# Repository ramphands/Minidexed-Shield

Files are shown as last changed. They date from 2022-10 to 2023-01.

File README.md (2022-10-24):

# Minidexed-Shield
A shield for a Raspberry Pi (Model 3) running [Minidexed](https://github.com/probonopd/MiniDexed/)
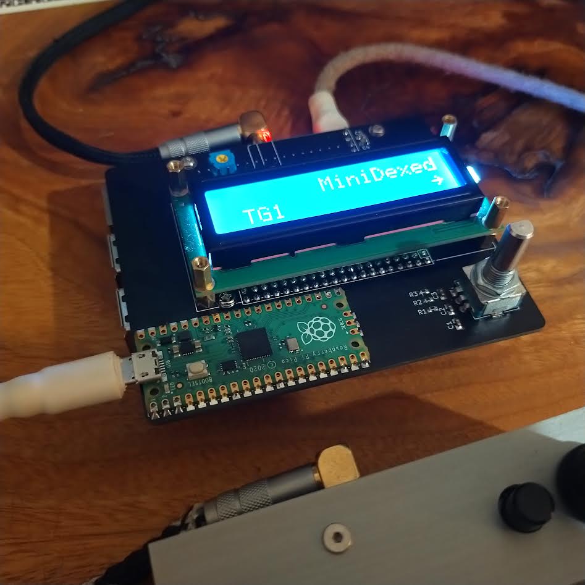
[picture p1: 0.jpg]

image of the shield in use

A Pi Pico is used as a Host to Host connection, allowing sequencing via PC or other host device.  Code obtained from [rsta2's "midi_adapter" Pico repo](https://github.com/rsta2/pico)

Please use the minixeded.ini file in this repo as the encoder pinout is different from the stock .ini

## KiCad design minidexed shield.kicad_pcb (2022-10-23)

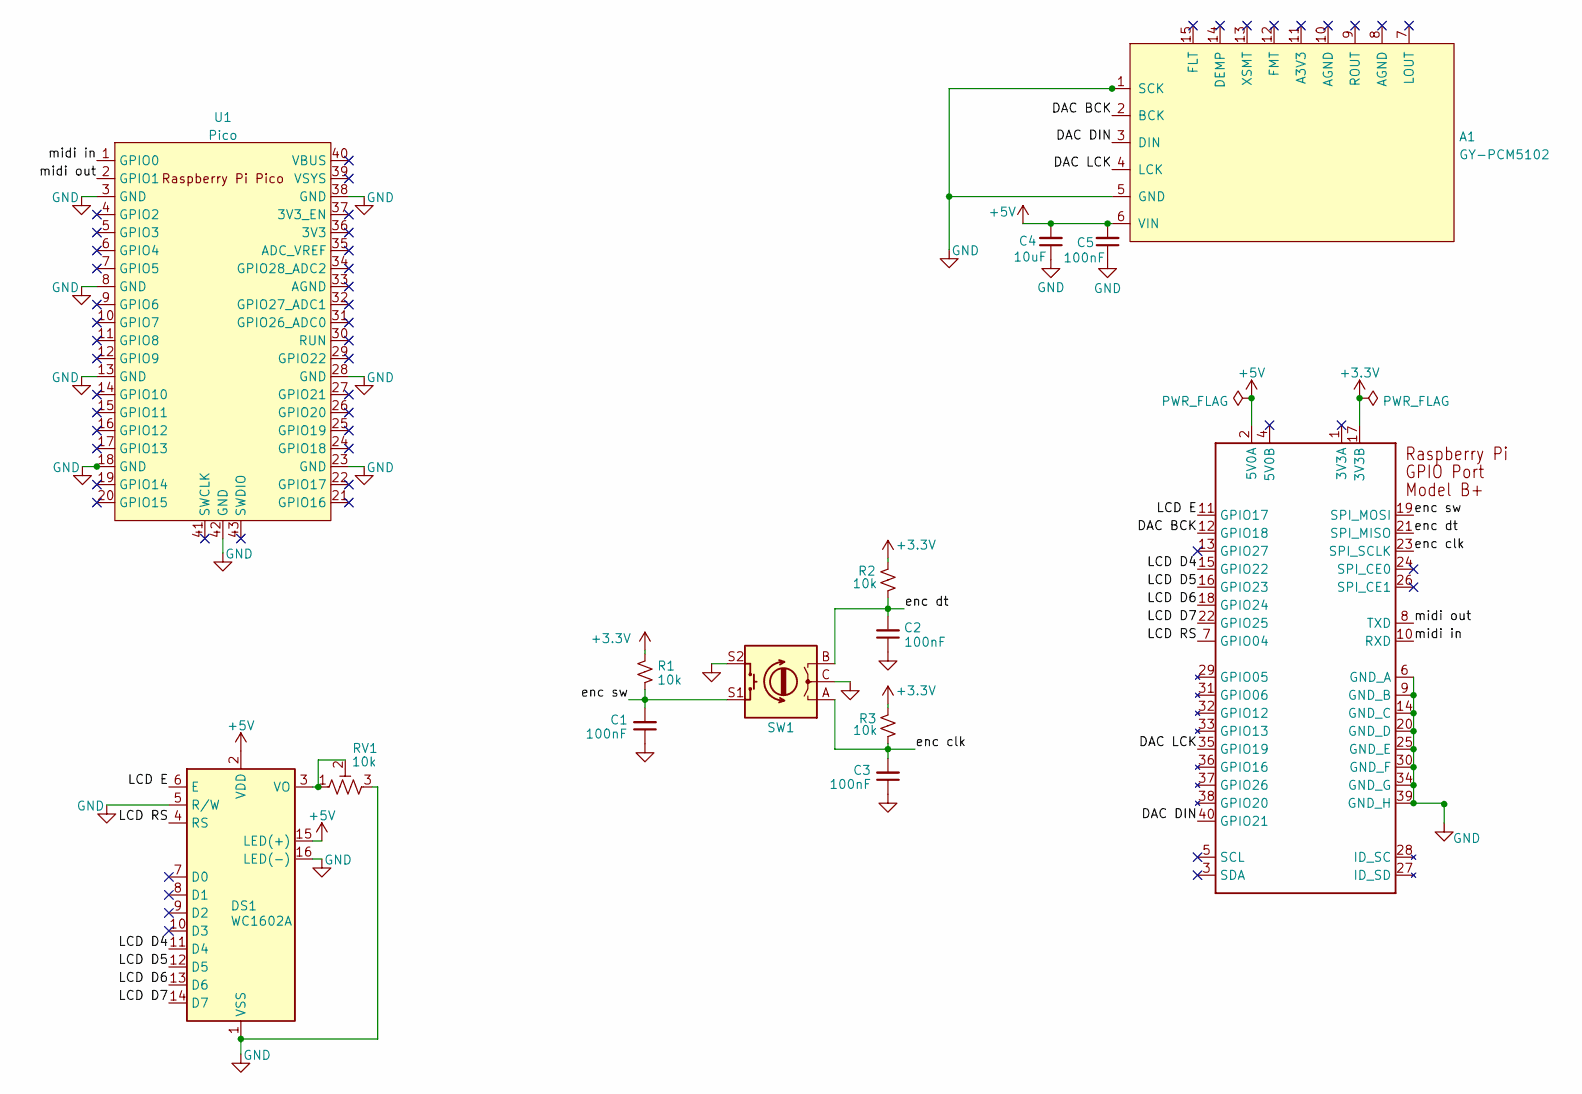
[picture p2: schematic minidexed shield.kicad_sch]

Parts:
A1: GY-PCM5102
C1, C2, C3, C5: 100nF; C0805
C4: 10uF; C0805
DS1: WC1602A
R1, R2, R3: 10k; R0603
RV1: 10k; TRIM_3362P-1-103
SW1: RotaryEncoder_Switch; RotaryEncoder_Alps_EC11E-Switch_Vertical_H20mm
U1: Pico; RPi_Pico_SMD_TH
X1: RASPI_BOARD_B+#_E0; RASPI_BOARD_B+_EDGES_3DRILL

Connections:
+3.3V: R1.1, R2.1, R3.2, X1.17 (3V3B)
+5V: A1.6 (VIN), C4.2, C5.2, DS1.2 (VDD), DS1.15 (LED(+)), X1.2 (5V0A)
/DAC BCK: A1.2 (BCK), X1.12 (GPIO18)
/DAC DIN: A1.3 (DIN), X1.40 (GPIO21)
/DAC LCK: A1.4 (LCK), X1.35 (GPIO19)
/LCD D4: DS1.11 (D4), X1.15 (GPIO22)
/LCD D5: DS1.12 (D5), X1.16 (GPIO23)
/LCD D6: DS1.13 (D6), X1.18 (GPIO24)
/LCD D7: DS1.14 (D7), X1.22 (GPIO25)
/LCD E: DS1.6 (E), X1.11 (GPIO17)
/LCD RS: DS1.4 (RS), X1.7 (GPIO04)
/enc clk: C3.2, R3.1, SW1.A, X1.23 (SPI_SCLK)
/enc dt: C2.2, R2.2, SW1.B, X1.21 (SPI_MISO)
/enc sw: C1.2, R1.2, SW1.S1, X1.19 (SPI_MOSI)
/midi in: U1.1 (GPIO0), X1.10 (RXD)
/midi out: U1.2 (GPIO1), X1.8 (TXD)
GND: A1.1 (SCK), A1.5 (GND), C1.1, C2.1, C3.1, C4.1, C5.1, DS1.1 (VSS), DS1.5 (R/W), DS1.16 (LED(-)), RV1.3, SW1.C, SW1.S2, U1.3 (GND), U1.8 (GND), U1.13 (GND), U1.18 (GND), U1.23 (GND), U1.28 (GND), U1.38 (GND), U1.42 (GND), X1.6 (GND_A), X1.9 (GND_B), X1.14 (GND_C), X1.20 (GND_D), X1.25 (GND_E), X1.30 (GND_F), X1.34 (GND_G), X1.39 (GND_H)
unnamed: DS1.3 (VO), RV1.1, RV1.2

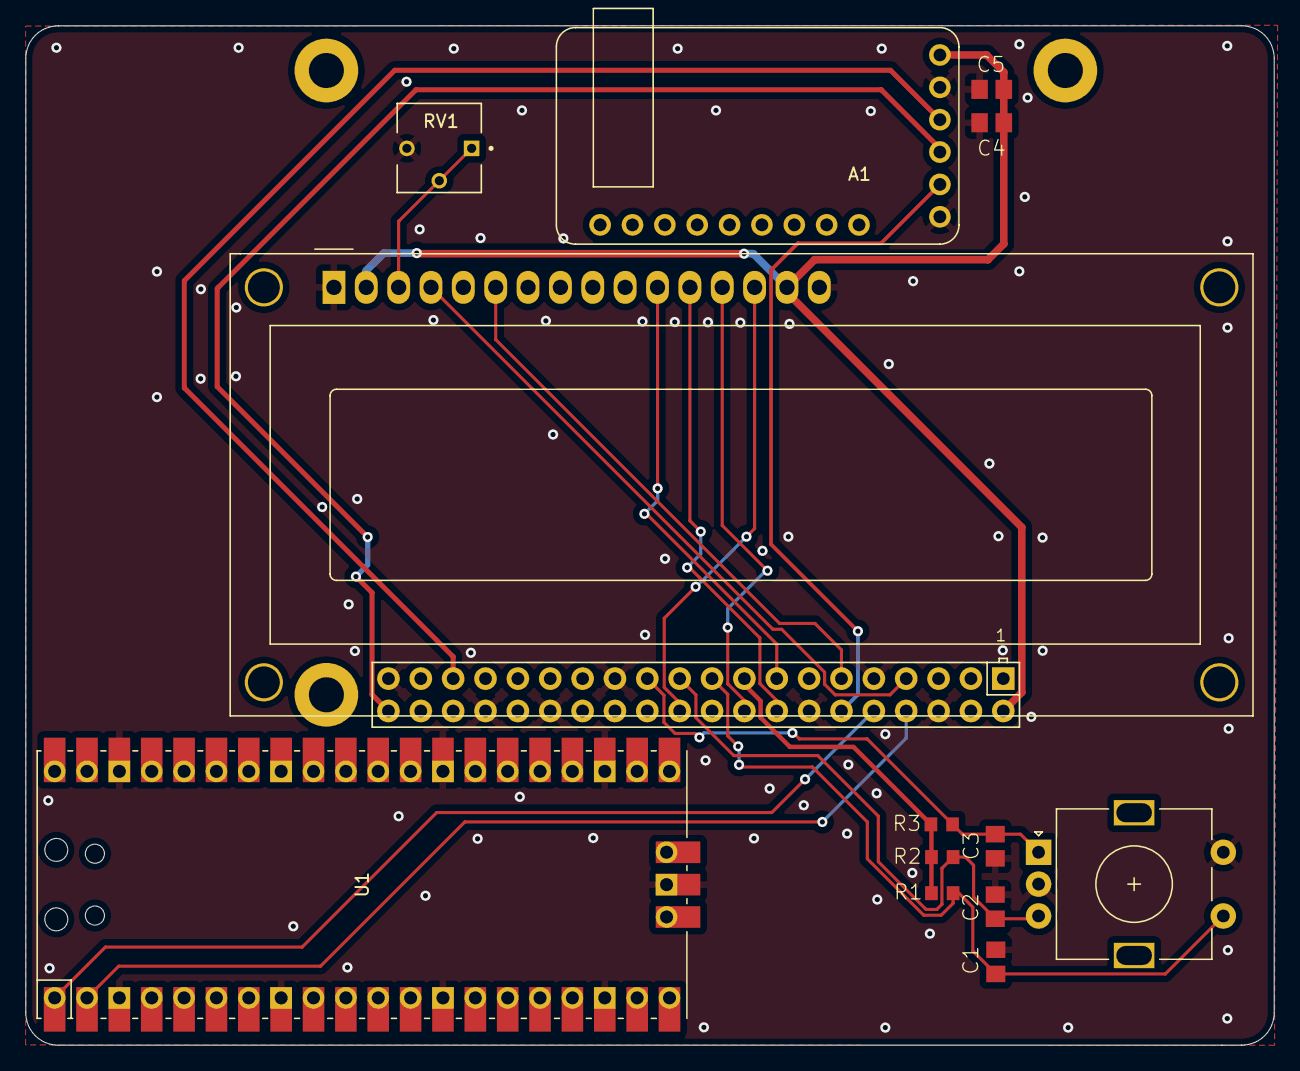
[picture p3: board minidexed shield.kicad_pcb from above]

Board: 2 copper layers, 98.0 x 80.0 mm, 14 parts (0 on the bottom side), 18 nets.

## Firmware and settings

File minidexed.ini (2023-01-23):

#
# minidexed.ini
#

# Sound device
SoundDevice=i2s
#SoundDevice=pwm
#SoundDevice=hdmi
SampleRate=48000
#ChunkSize=256
DACI2CAddress=0
ChannelsSwapped=1

# MIDI
MIDIBaudRate=31250
#MIDIThru=umidi1,ttyS1
MIDIRXProgramChange=1
IgnoreAllNotesOff=0
MIDIAutoVoiceDumpOnPC=1

# HD44780 LCD
LCDEnabled=1
LCDPinEnable=17
LCDPinRegisterSelect=4
LCDPinReadWrite=0
LCDPinData4=22
LCDPinData5=23
LCDPinData6=24
LCDPinData7=25
LCDI2CAddress=0x00

# SSD1306 LCD
# For a 128x32 display, set LCDColumns=20; LCDRows=2
# For a 128x64 display, set LCDColumns=20; LCDRows=4
SSD1306LCDI2CAddress=0x0
SSD1306LCDWidth=128
SSD1306LCDHeight=32
SSD1306LCDRotate=0
SSD1306LCDMirror=0

# Default is 16x2 display (e.g. HD44780)
LCDColumns=16
LCDRows=2

# GPIO Button Navigation
#  Any buttons set to 0 will be ignored
ButtonPinPrev=0
ButtonActionPrev=
ButtonPinNext=0
ButtonActionNext=
ButtonPinBack=10
ButtonActionBack=longpress
ButtonPinSelect=10
ButtonActionSelect=click
ButtonPinHome=10
ButtonActionHome=doubleclick
ButtonPinShortcut=10
# (Shortcut doesn't have an action)

# Timeouts in milliseconds for double click and long press
DoubleClickTimeout=400
LongPressTimeout=400

# MIDI Button Navigation
#  Specify MIDI CC to act as a button
#  NB: Off < 64 < ON
# CC channel: 0=OFF; 1-16 MIDI Ch; >16 Omni
# If MIDIButtonNotes>0 then treat MIDIButton
# numbers as MIDI Note numbers note CC numbers.
MIDIButtonCh=0
MIDIButtonNotes=0
MIDIButtonNotes=1
MIDIButtonPrev=00
MIDIButtonNext=02
MIDIButtonBack=03
MIDIButtonSelect=04
MIDIButtonHome=06
# KY-040 Rotary Encoder
EncoderEnabled=1
EncoderPinClock=11
EncoderPinData=9

# Debug
MIDIDumpEnabled=0
ProfileEnabled=0

# Performance
PerformanceSelectToLoad=1
